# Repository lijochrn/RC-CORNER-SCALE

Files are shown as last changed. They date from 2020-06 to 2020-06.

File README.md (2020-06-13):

# RC-CORNER-SCALE
Arduino based RC Corner Weight Scale. DIY/Cheap Solution
Hello All,
Lets make a DIY RC-CORNER-WEIGHT SCALE

Items Needed

1. Load Cell 2 Kg -  4

2. HX711 ADC Module -  4

3. Arduino Uno -1

4. LCD 16X2 i2c – 1

5. Cables- as required

6. Soldering Iron

7. Push Buttons - 2

8. Plastic box -1

9. Resistor 220KOhms - 2 nos

Steps involved.

1. Wire the Loadcell, ADC and Arduino as in the picture. Fritz file is attacthed.

2. Download the LCD and HX711 ADC library and include in the IDE project.

HX711_ADC Library https://github.com/olkal/HX711_ADC
LCD i2C Library https://www.arduinolibraries.info/libraries/liquid-crystal-i2-c

3. Calibrating the Loadcell's

Before using Loadcells for measuring each of them have to be calibrated.

For that open the sketch "Calibration" from Examples of HX711_ADC library.

Edit the calibration file Dout as A0 and SCK as 2. Uploading this sketch will calibrate the Front Right Loadcell Only.

Download the calibraion sketch to Arduino and open the Serial Plotter. 
[Select correct baudrate, else messages wont be displayed correctly]. 

Ensure no loads are placed on loadcell, enter "t" and send. Tare operation is performed. 

Place a known weight on the platform. For example I have placed 60.0 grams enter 60.0 and send.

Calibration factor for the this loadcell will be displayed.

Note the Calibration factor. 

Edit the calibration file Dout as A1 and SCK as 3. Uploading this sketch will calibrate the Front Left Loadcell Only.

Note the Calibration factor. 

Repeat the steps for other two loadcells.

4. Copy paste the code.

Note: Edit the calibration factor obtained for each laodcell in main sketch.

  calibrationValue_1 = 1070.13; 
	
  calibrationValue_2 = 1145.97; 
	
  calibrationValue_3 = 1154.0; 
	
  calibrationValue_4 = 1056.95; 
	
In my case above values are obtained. You must Enter your loadcell's value else it wont work correctly.

5. Upload.

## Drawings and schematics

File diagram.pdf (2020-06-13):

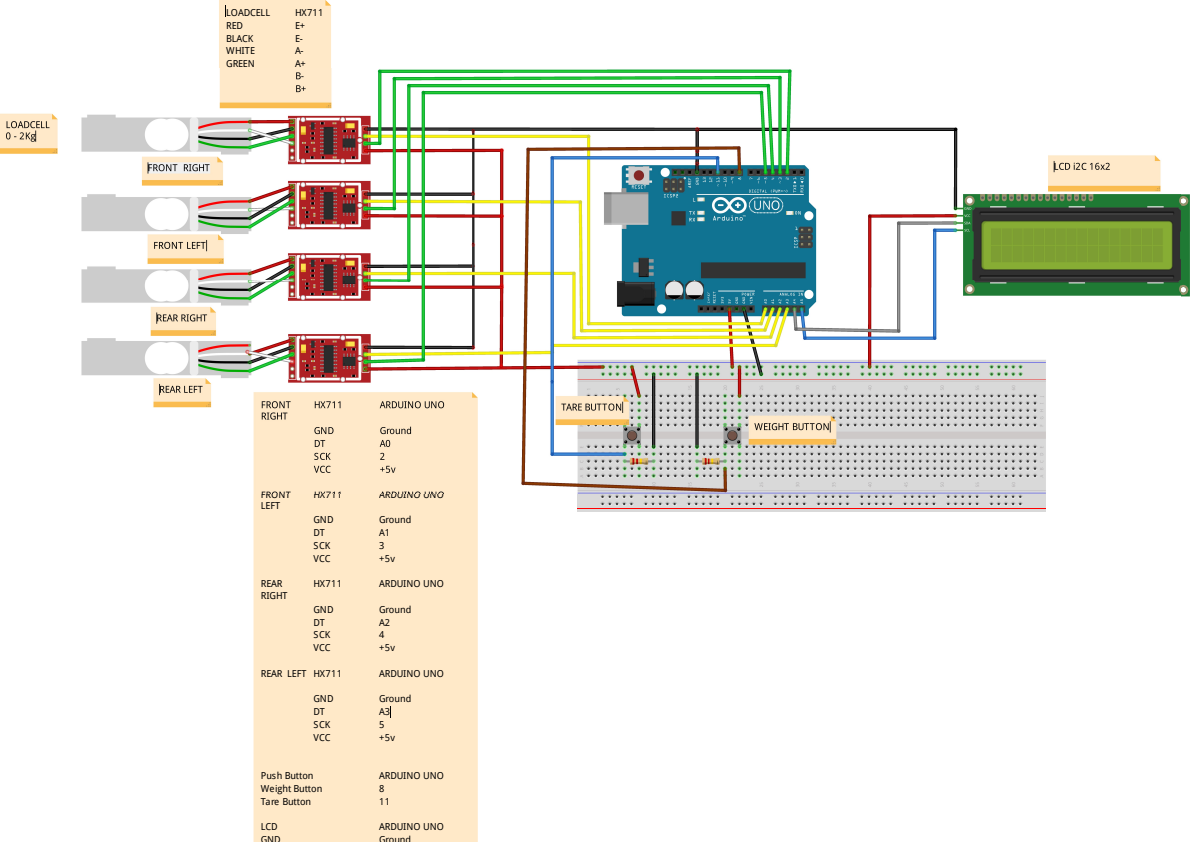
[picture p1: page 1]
LOADCELL; RED; BLACK; WHITE; GREEN; FRONT LEFT; ARDUINO UNO; GND; Ground; SCK; VCC; REAR RIGHT; REAR LEFT HX711; Push Button; Weight Button; Tare Button; LCD

GND | Ground
VCC | +5v
SDA | A4
SCL | A5

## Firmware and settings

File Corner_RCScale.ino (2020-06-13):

#include <LiquidCrystal_I2C.h>
#include <HX711_ADC.h>

LiquidCrystal_I2C lcd(0x27,20,2);  // set the LCD address to 0x27 for a 16 chars and 2 line display


char Telecom[32] = {'P','R','E','S','S',' ','T','A','R','E',' ','B','U','T','T','O','N',' ','T','O',' ','C','O','N','T','I','N','U','E','!','!',' '};

int ModeButton = 11;             // Button connected to digital pin 11 acts as mode/tare selection
int WtButton = 8;                // Button connected to digital pin 8 acts as Weight/Total Weight display

int L1DOUT = A0;              // LOADCELL connected to ANALOG INPUT 0  //Front Right  DOUT
int L1SCK = 2;              // LOADCELL connected to DIGITAL INPUT 2  //Front Right  SCK

int L2DOUT = A1;              // LOADCELL connected to ANALOG INPUT 1  //Front Left  DOUT
int L2SCK = 3;              // LOADCELL connected to DIGITAL INPUT 3  //Front Left  SCK

int L3DOUT = A2;              // LOADCELL connected to ANALOG INPUT 2  //Back Right  DOUT
int L3SCK = 4;              // LOADCELL connected to DIGITAL INPUT 4  //Back Right  SCK

int L4DOUT = A3;              // LOADCELL connected to ANALOG INPUT 3//Back Left  DOUT
int L4SCK = 5;              // LOADCELL connected to DIGITAL INPUT 5  //Back Left  SCK

int presscount = 0;              // Counting how many Wtbutton press has performed
int buttonState = 0;             // current state of the Wtbutton
int lastButtonState = 0;         // previous state of the Wtbutton
int modestate = 0;

//HX711 constructor (dout pin, sck pin)
HX711_ADC Loadcell_1(L1DOUT, L1SCK); //Load Cell 1 Front Right
HX711_ADC Loadcell_2(L2DOUT, L2SCK); //Load Cell 2 Front Left
HX711_ADC Loadcell_3(L3DOUT, L3SCK); //Load Cell 3 Back Right
HX711_ADC Loadcell_4(L4DOUT, L4SCK); //Load Cell 4 Back Left

//const int calVal_eepromAdress_1 = 0; // eeprom adress for calibration value load cell 1 (4 bytes)
//const int calVal_eepromAdress_2 = 4; // eeprom adress for calibration value load cell 2 (4 bytes)
//const int calVal_eepromAdress_3 = 8; // eeprom adress for calibration value load cell 3 (4 bytes)
//const int calVal_eepromAdress_4 = 12; // eeprom adress for calibration value load cell 4 (4 bytes)
long t;
float weight_FR=0.0;
float weight_FL=0.0;
float weight_BR=0.0;
float weight_BL=0.0;
float weight_F=0.0;
float weight_B=0.0;
float totalwt=0.0;
float weight_FRBL=0.0;
float weight_FLBR= 0.0;
float percnt_F = 0.0;
float percnt_B = 0.0;
void setup()
{
  pinMode(ModeButton, INPUT);      // sets the digital pin as input
  pinMode(WtButton, INPUT);       // sets the digital pin as input
  pinMode(6, OUTPUT); 

  lcd.init();                     // initialize the lcd   
  lcd.backlight(); 
  lcd.setCursor(2,0);
  lcd.print("<<WELCOME>>"); 
  lcd.setCursor(1,1);
  lcd.print("CORNER WEIGHT"); 
  delay(2000);
  lcd.setCursor(2,0);
  lcd.print("Initiating..");   
  float calibrationValue_1; // calibration value load cell 1 Front Right
  float calibrationValue_2; // calibration value load cell 2 Front Left
  float calibrationValue_3; // calibration value load cell 3 Back Right
  float calibrationValue_4; // calibration value load cell 4 Back Left
  calibrationValue_1 = 1070.13; 
  calibrationValue_2 = 1145.97; 
  calibrationValue_3 = 1154.0; 
  calibrationValue_4 = 1056.95; //1132.28

#if defined(ESP8266) || defined(ESP32)
  //EEPROM.begin(512); // uncomment this if you use ESP8266 and want to fetch the value from eeprom
#endif
  //EEPROM.get(calVal_eepromAdress_1, calibrationValue_1); // uncomment this if you want to fetch the value from eeprom
  //EEPROM.get(calVal_eepromAdress_2, calibrationValue_2); // uncomment this if you want to fetch the value from eeprom 
  //EEPROM.get(calVal_eepromAdress_3, calibrationValue_3); // uncomment this if you want to fetch the value from eeprom
  //EEPROM.get(calVal_eepromAdress_4, calibrationValue_4); // uncomment this if you want to fetch the value from eeprom 

  
  Loadcell_1.begin(); // start connection to HX711 1 Front Right
  Loadcell_2.begin(); // start connection to HX711 2 Front Left
  Loadcell_3.begin(); // start connection to HX711 3 Back Right
  Loadcell_4.begin(); // start connection to HX711 4 Back Left
  
  long stabilizingtime = 2000; // tare preciscion can be improved by adding a few seconds of stabilizing time
  boolean _tare = true; //set this to false if you don't want tare to be performed in the next step
  byte loadcell_1_rdy = 0;
  byte loadcell_2_rdy = 0;
  byte loadcell_3_rdy = 0;
  byte loadcell_4_rdy = 0;


  lcd.clear(); 
  lcd.setCursor(1,0);
  lcd.print("LOADCELL CHECK");  
  lcd.setCursor(3,1);
  lcd.print("CONNECTION");  

  while ((loadcell_1_rdy + loadcell_2_rdy + loadcell_3_rdy + loadcell_4_rdy) < 4) { //run startup, stabilization and tare, both modules simultaniously
    if (!loadcell_1_rdy) loadcell_1_rdy = Loadcell_1.startMultiple(stabilizingtime, _tare);
    if (!loadcell_2_rdy) loadcell_2_rdy = Loadcell_2.startMultiple(stabilizingtime, _tare);
    if (!loadcell_3_rdy) loadcell_3_rdy = Loadcell_3.startMultiple(stabilizingtime, _tare);
    if (!loadcell_4_rdy) loadcell_4_rdy = Loadcell_4.startMultiple(stabilizingtime, _tare);    
  }

  lcd.clear(); 
  
  if (Loadcell_1.getTareTimeoutFlag()) {
    lcd.setCursor(0,0);
    lcd.print("CHECK WIRING OF"); 
    lcd.setCursor(0,1);
    lcd.print("LOADCELL 1 FR"); 
     delay(1000);    
  }
  if (Loadcell_2.getTareTimeoutFlag()) {
    lcd.setCursor(0,0);
    lcd.print("CHECK WIRING OF"); 
    lcd.setCursor(0,1);
    lcd.print("LOADCELL 2 FL"); 
     delay(1000);  
  }
   if (Loadcell_3.getTareTimeoutFlag()) {
    lcd.setCursor(0,0);
    lcd.print("CHECK WIRING OF"); 
    lcd.setCursor(0,1);
    lcd.print("LOADCELL 3 BR"); 
     delay(1000);    
  }
  if (Loadcell_4.getTareTimeoutFlag()) {
    lcd.setCursor(0,0);
    lcd.print("CHECK WIRING OF"); 
    lcd.setCursor(0,1);
    lcd.print("LOADCELL 4 FL"); 
     delay(2000);  
  }
  
  Loadcell_1.setCalFactor(calibrationValue_1); // user set calibration value (float)
  Loadcell_2.setCalFactor(calibrationValue_2); // user set calibration value (float)
  Loadcell_3.setCalFactor(calibrationValue_3); // user set calibration value (float)
  Loadcell_4.setCalFactor(calibrationValue_4); // user set calibration value (float)

  
  lcd.clear();
  lcd.setCursor(0,0);
  lcd.print("STARTUP COMPLETE");     
  delay(2000);  
  lcd.clear(); 
}


void loop()
{

  static boolean newDataReady = 0;
  const int serialPrintInterval = 0; //increase value to slow down serial print activity

  // check for new data/start next conversion:
  if (Loadcell_1.update()) newDataReady = true;
  Loadcell_2.update();
  Loadcell_3.update();
  Loadcell_4.update();

  //get smoothed value from data set
  if ((newDataReady)) {
    if (millis() > t + serialPrintInterval) {
      float FR = Loadcell_1.getData();           // Read Analog Value from loadcell 1 to FR internal register.
      weight_FR= FR;
      
      float FL = Loadcell_2.getData(); 
      weight_FL= FL;
      
      float BR = Loadcell_3.getData(); 
      weight_BR= BR;

      float BL = Loadcell_4.getData(); 
      weight_BL= BL;
      
      weight_F= weight_FR+weight_FL;        // Calculating total weight of FRONT in grams
      weight_B= weight_BR+weight_BL;        // Calculating total weight of BACK in grams
      totalwt= weight_F+weight_B;           // Calculating total weight of chassis

      weight_FRBL= weight_FR+weight_BL;        // Calculating total weight of FRONT RIGHT AND BACK LEFT in grams
      weight_FLBR= weight_BR+weight_FL;        // Calculating total weight of FRONT LEFT AND BACK RIGHT in grams
      float totalCRNRwt= weight_FRBL+weight_FLBR;    // Calculating CORNER EACH weight of chassis

      percnt_F = weight_F*(100.0/totalwt);  // Calculating total weight % of Front area
      percnt_B = weight_B*(100.0/totalwt);  // Calculating total weight % of Back area

      newDataReady = 0;
      t = millis();
    }
  }

buttonState = digitalRead(WtButton); // read the pushbutton input pin:
modestate = digitalRead(ModeButton); // read the pushbutton input pin:

//------Calling TARE Function if TARE button is pressed
if (modestate == HIGH) {
  tare ();
}
//--------------------------------------   


      
  if (buttonState != lastButtonState) {   // compare the buttonState to its previous state
    // if the state has changed, increment the counter
    if (buttonState == HIGH) {
      // if the current state is HIGH then the button
      // went from off to on:
        presscount++;
        lcd.clear(); 
        }
          
    delay(50);  // Delay a little bit to avoid bouncing
  }    

lastButtonState = buttonState; // save the current state as the last state,for next time through the loop

switch (presscount) {
    case 0:    
      lcd.setCursor(2,0);
      lcd.print("PRESS BUTTON");  
      lcd.setCursor(4,1);
      lcd.print("TOGGLE");  
      
      break;
    case 1:    // WEIGHT OF EACH TIRE
      lcd.setCursor(0,0);
      lcd.print(String("FR ") + String(weight_FR));  
      lcd.setCursor(8,0);
      lcd.print(String("BR ") + String(weight_BR));
            /////
      lcd.setCursor(0,1);
      lcd.print(String("FL ") + String(weight_FL)); 
      lcd.setCursor(8,1);
      lcd.print(String("BL ") + String(weight_BL));
      
      break;
    case 2:   // WEIGHT OF FRONT AND REAR & TOTAL WEIGHT
      lcd.setCursor(0,0);
      lcd.print(String("F=") + String(weight_F));  
      lcd.setCursor(8,0);
      lcd.print(String("B=") + String(weight_B));
            /////
      lcd.setCursor(2,1);
      lcd.print(String("TOTAL=") + String(totalwt) + String("g"));   
         
      break;     
    case 3:    // TWO CORNER WEIGHTS
      lcd.setCursor(2,0);
      lcd.print(String("FR+BL=") + String(weight_FRBL));  
      lcd.setCursor(2,1);
      lcd.print(String("FL+BR=") + String(weight_FLBR));
      break;
    case 4:    // WEIGHT DISTRIBUTION %  OF FRONT AND REAR 
      
      lcd.setCursor(2,0);
      lcd.print(String("FRONT=") + String(percnt_F) + String("%"));  
      lcd.setCursor(2,1);
      lcd.print(String("BACK =") + String(percnt_B) + String("%"));                   
      break;
    case 5:    // GO BACK 
      presscount = 1;
    break;
}

}

void tare(){
//Function for TARE operation   
      lcd.clear(); 
      lcd.setCursor(1,0);
      lcd.print("TARE OPERATION");  
      lcd.setCursor(4,1);
      lcd.print("STARTING"); 
      delay(2000); 
      lcd.setCursor(0,0);
      lcd.print("REMOVE ALL LOAD");  
      lcd.setCursor(3,1);
      lcd.print("FROM TRAYS"); 
      delay(2000); 
      modestate = digitalRead(ModeButton); // read the pushbutton input pin:

// Delay for REMOVING load from all trays, system conitue only on TARE button ptess.
// Below code for LCD scrolling[Message types in chracter Array[Telecom] of 32 length  from right to left
      while (modestate == LOW) {
      lcd.setCursor(0,1);  
      for (int j=0;j<=31;j++)
      {
      lcd.print(Telecom[j]); 
      }
      lcd.setCursor(0,1);
      delay(250);
      int swap = Telecom[0];
      for (int i=0;i<31;i++)
      {
      Telecom[i] = Telecom[i+1]; 
      }
      Telecom[31] = swap; 
      modestate = digitalRead(ModeButton); // read the pushbutton input pin:    
      }
/////////////////////////////// LCD scrolling code ends.

      Loadcell_1.tareNoDelay();
      Loadcell_2.tareNoDelay();
      Loadcell_3.tareNoDelay();
      Loadcell_4.tareNoDelay(); 
            
      presscount = 0;     
   
  //check if last tare operation is complete
  if (Loadcell_1.getTareStatus() == true) {
       lcd.clear();
       lcd.setCursor(1,0);
       lcd.print("TARE FRLOADCELL");  
       lcd.setCursor(4,2);
       lcd.print("COMPLETE");
        delay(1000);      
  }
  if (Loadcell_2.getTareStatus() == true) {
       lcd.setCursor(1,0);
       lcd.print("TARE FLLOADCELL");  
       lcd.setCursor(4,2);
       lcd.print("COMPLETE");
       delay(1000);  
  }
  if (Loadcell_3.getTareStatus() == true) {
       lcd.setCursor(1,0);
       lcd.print("TARE BRLOADCELL");  
       lcd.setCursor(4,2);
       lcd.print("COMPLETE");
       delay(1000);  
  }    
  if (Loadcell_4.getTareStatus() == true) {
       lcd.setCursor(1,0);
       lcd.print("TARE BLLOADCELL");  
       lcd.setCursor(4,2);
       lcd.print("COMPLETE");
       delay(1000);  
  }  
   lcd.clear();
}
